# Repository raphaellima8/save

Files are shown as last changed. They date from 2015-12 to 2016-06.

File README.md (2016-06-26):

# SAVE – Um sistema FLOSS autônomo para evitar acidentes envolvendo crianças em carros estacionados

## Sobre
SAVE é um sistema autônomo para evitar acidentes envolvendo crianças em carros estacionados.

## Organização dos diretórios
1. src: Código fonte do firmware e esquemáticos do sistema
	* firmware:   Código fonte do firmware
	* schematics: Arquivos de projeto (software Eagle) dos esquemáticos e layout da PCB

2. dist: Arquivos de distribuição
	* firmware: Versão .hex do firmware para gravação na placa Arduino UNO
	* schematics: Versões em PDF do esquemáticos e layouts da PCB para impressão

## Contato
* Raphael Lima: raphael.aolima8 at gmail dot com

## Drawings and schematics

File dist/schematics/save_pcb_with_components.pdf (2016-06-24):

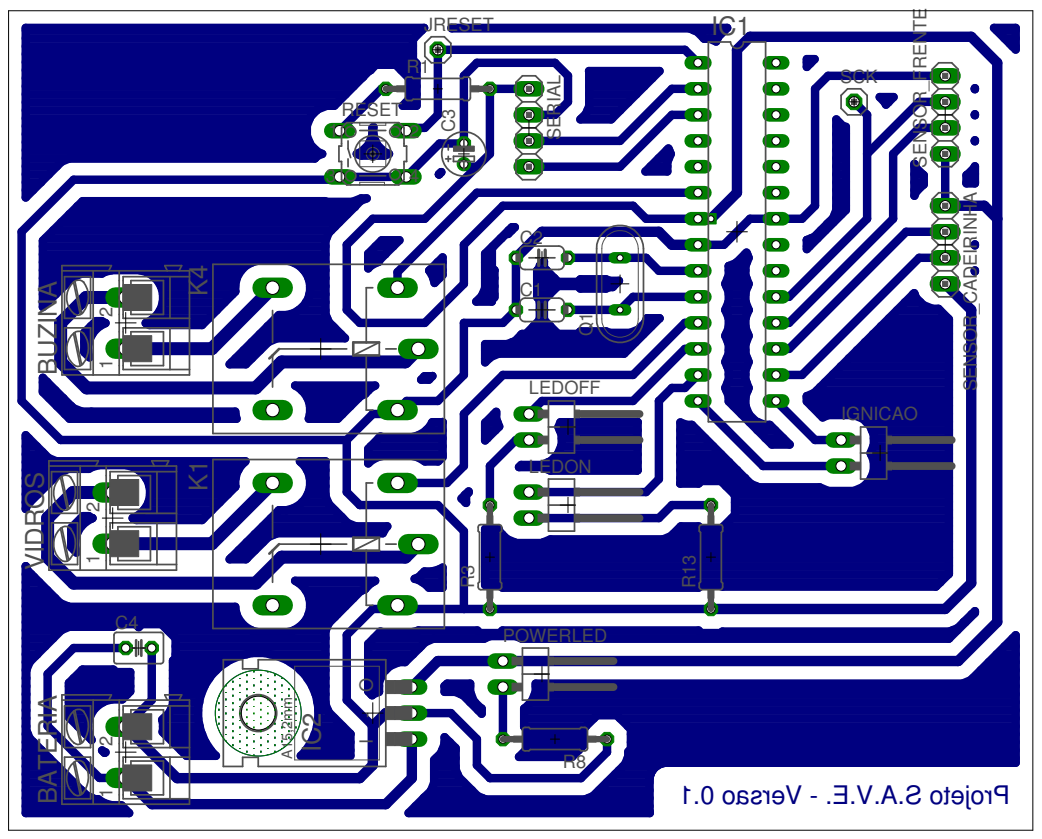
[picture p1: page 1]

11. 0 oasr eV- . E. V. A. S ot ej or P 2 1 2 A15,2mm 1 2 - I O 1 2 3 4 BATERIA BUZINAC1 C2 C3 C4 IC1 IC2 IGNICAO JRESET K1 K4 LEDOFF LEDON POWERLEDQ1 R1 R13 R3 R8 RESET SCK SENSOR_CADEIRINHA SENSOR_FRENTE SERIAL VIDROS

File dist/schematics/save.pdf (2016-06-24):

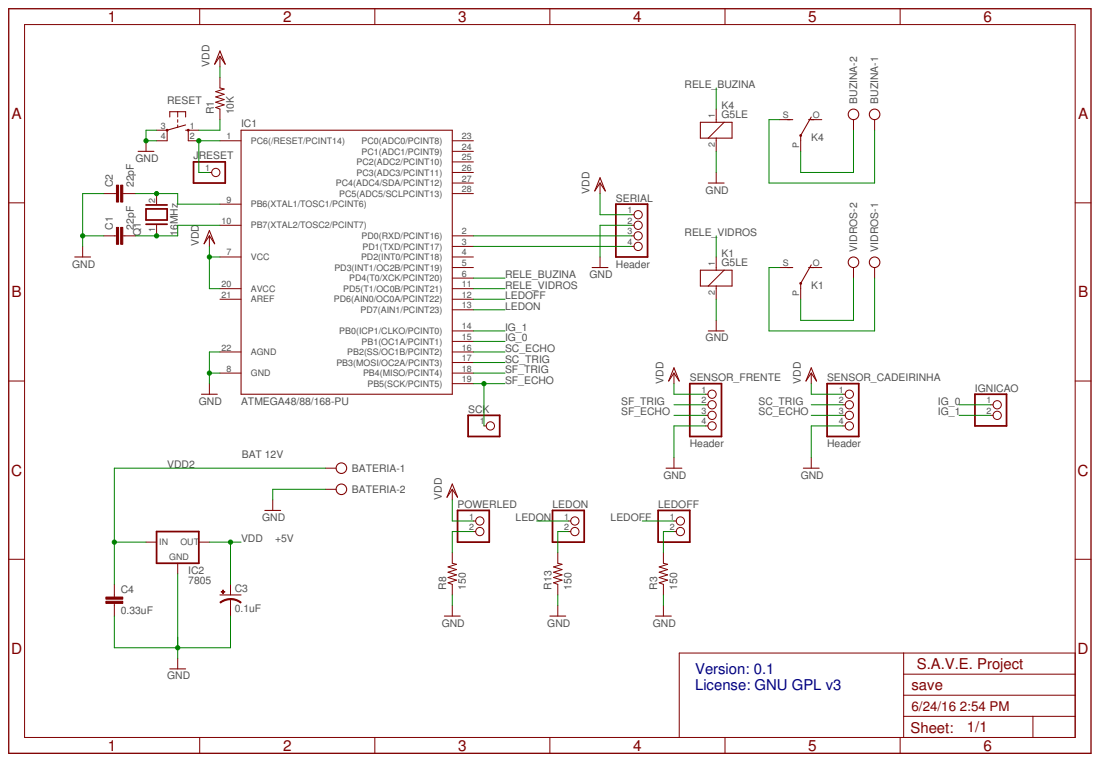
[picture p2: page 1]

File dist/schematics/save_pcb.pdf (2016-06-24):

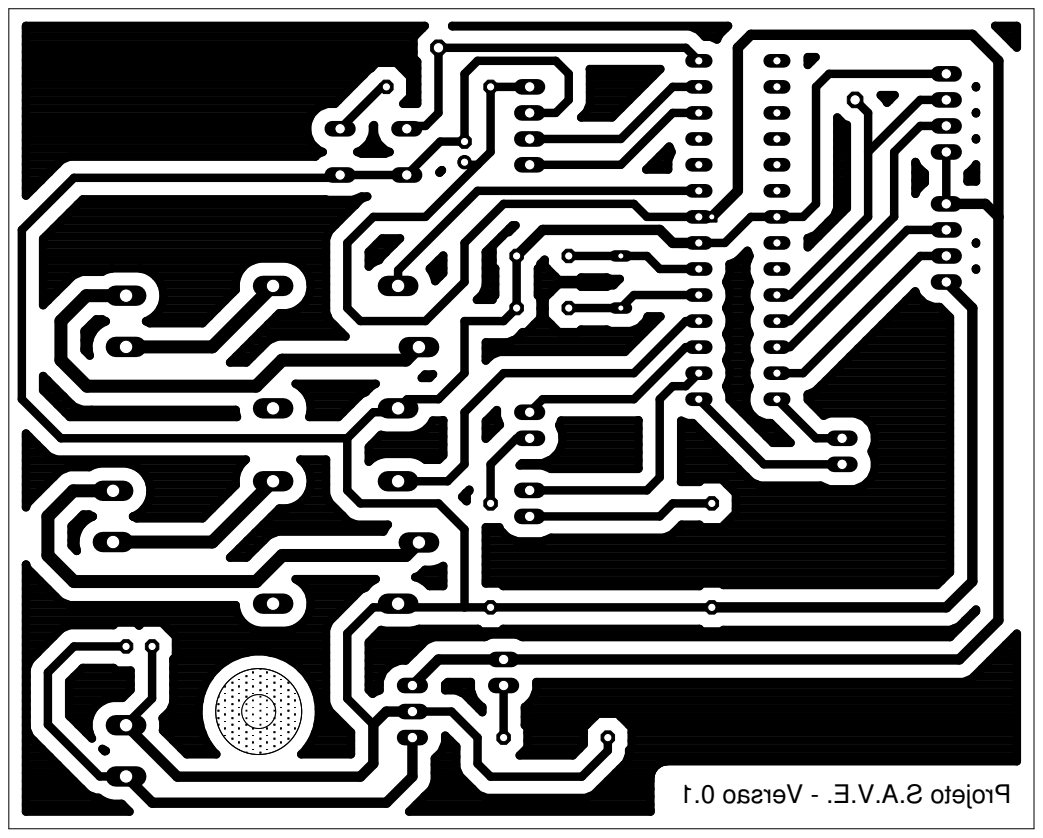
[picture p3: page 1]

1. 0 oasr eV- . E. V. A. S ot ej or P

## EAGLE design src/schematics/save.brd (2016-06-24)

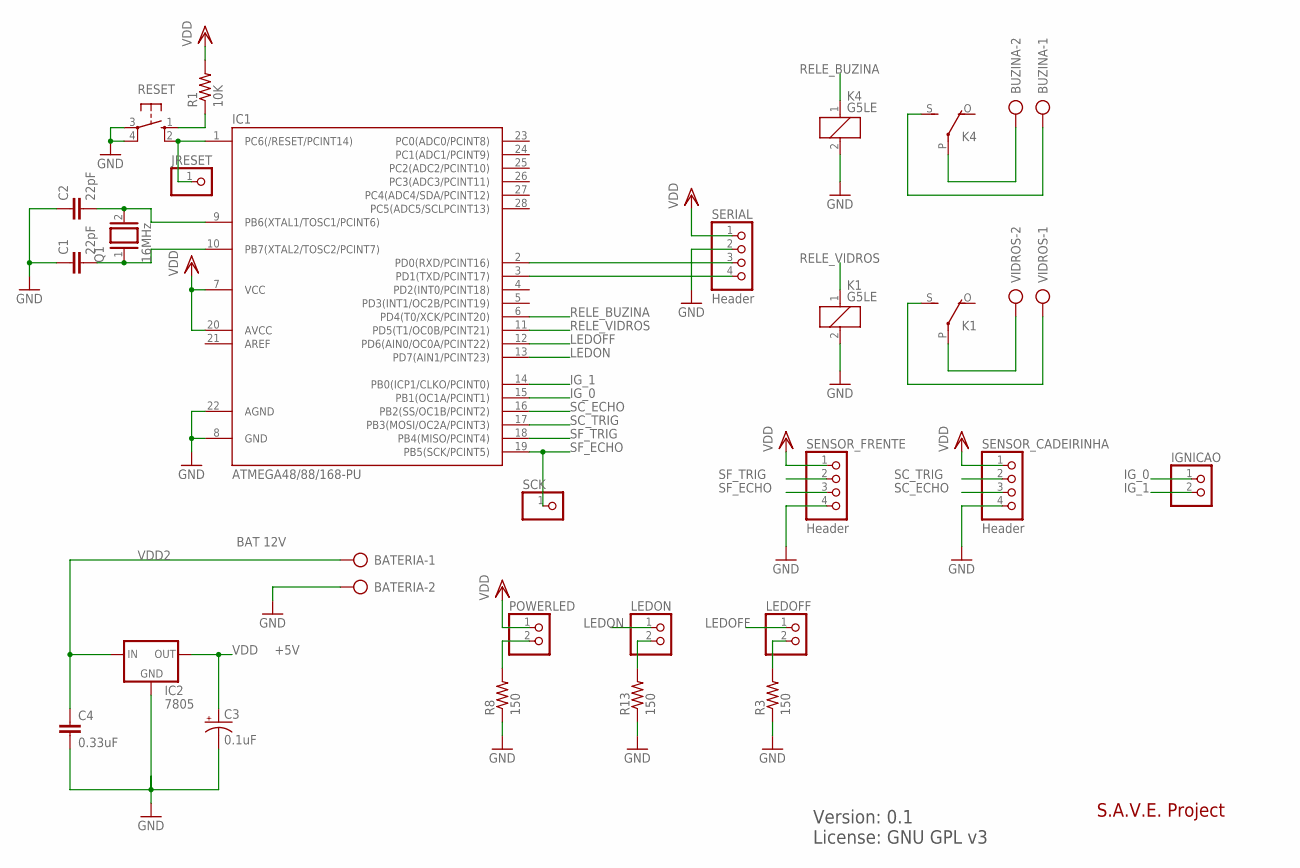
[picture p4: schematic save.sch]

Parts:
BATERIA: AK300/2
BUZINA: AK300/2
C1, C2: 22pF; C050-024X044
C3: 0.1uF; E2-4
C4: 0.33uF; C025-030X050
IC1: ATMEGA48/88/168-PU; DIL28-3
IC2: 7805; 78XXL
IGNICAO: PINHD-1X2/90; 1X02/90
JRESET: PINHD-1X1; 1X01
K1, K4: G5LE
LEDOFF: PINHD-1X2/90; 1X02/90
LEDON: PINHD-1X2/90; 1X02/90
POWERLED: PINHD-1X2/90; 1X02/90
Q1: 16MHz; QS
R1: 10K; 0207/10
R3, R8, R13: 150; 0207/10
RESET: 10-XX; B3F-10XX
SCK: PINHD-1X1; 1X01
SENSOR_CADEIRINHA: Header; 1X04
SENSOR_FRENTE: Header; 1X04
SERIAL: Header; 1X04
VIDROS: AK300/2

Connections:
BUZINA-2: BUZINA.2, K4.P
GND: BATERIA.2, C1.1, C2.1, C3.-, C4.2, IC1.8 (GND), IC1.22 (AGND), IC2.GND, K1.2, K4.2, R3.1, R8.1, R13.1, RESET.3, RESET.4 (P1), SENSOR_CADEIRINHA.4, SENSOR_FRENTE.4, SERIAL.2
IG_0: IC1.15 (PB1(OC1A/PCINT1)), IGNICAO.1
IG_1: IC1.14 (PB0(ICP1/CLKO/PCINT0)), IGNICAO.2
LEDOFF: IC1.12 (PD6(AIN0/OC0A/PCINT22)), LEDOFF.1
LEDON: IC1.13 (PD7(AIN1/PCINT23)), LEDON.1
unnamed: BUZINA.1, K4.S
unnamed: R1.1, RESET.1 (S)
unnamed: IC1.1 (PC6(/RESET/PCINT14)), JRESET.1, RESET.2 (S1)
unnamed: C1.2, IC1.10 (PB7(XTAL2/TOSC2/PCINT7)), Q1.1
unnamed: C2.2, IC1.9 (PB6(XTAL1/TOSC1/PCINT6)), Q1.2
unnamed: K1.S, VIDROS.1
unnamed: LEDOFF.2, R3.2
unnamed: K1.P, VIDROS.2
unnamed: POWERLED.2, R8.2
unnamed: LEDON.2, R13.2
RELE_BUZINA: IC1.6 (PD4(T0/XCK/PCINT20)), K4.1
RELE_VIDROS: IC1.11 (PD5(T1/OC0B/PCINT21)), K1.1
RX: IC1.2 (PD0(RXD/PCINT16)), SERIAL.3
SC_ECHO: IC1.16 (PB2(SS/OC1B/PCINT2)), SENSOR_CADEIRINHA.3
SC_TRIG: IC1.17 (PB3(MOSI/OC2A/PCINT3)), SENSOR_CADEIRINHA.2
SF_ECHO: IC1.19 (PB5(SCK/PCINT5)), SCK.1, SENSOR_FRENTE.3
SF_TRIG: IC1.18 (PB4(MISO/PCINT4)), SENSOR_FRENTE.2
TX: IC1.3 (PD1(TXD/PCINT17)), SERIAL.4
VDD: C3.+, IC1.7 (VCC), IC1.20 (AVCC), IC2.OUT, POWERLED.1, R1.2, SENSOR_CADEIRINHA.1, SENSOR_FRENTE.1, SERIAL.1
VDD2: BATERIA.1, C4.1, IC2.IN

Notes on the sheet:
+5V
BAT 12V
S.A.V.E. Project
Version: 0.1 License: GNU GPL v3

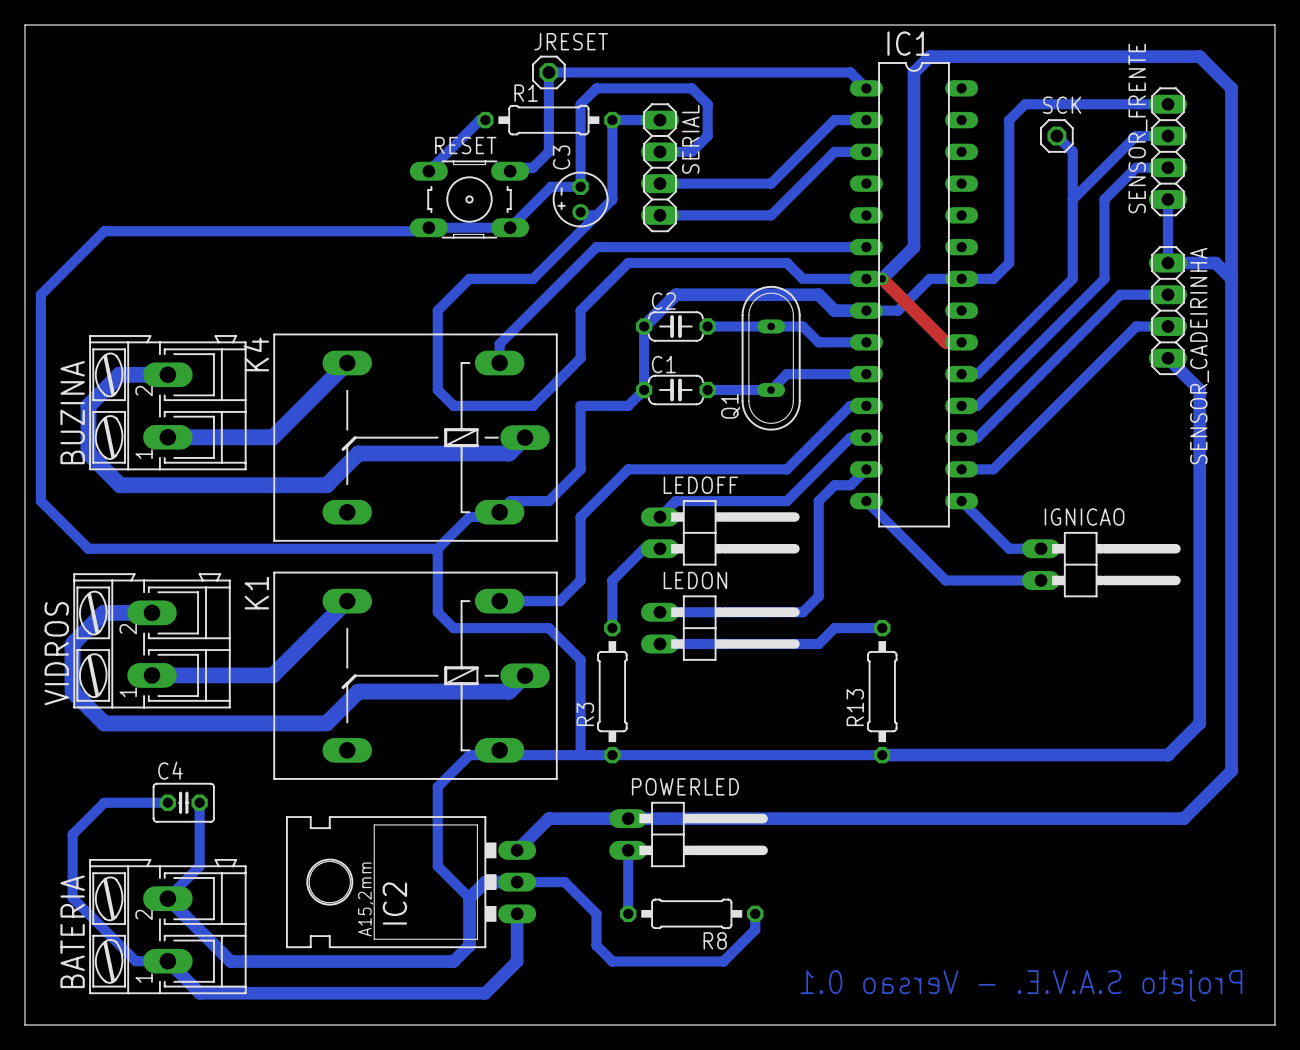
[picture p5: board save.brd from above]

Board: 2 copper layers, 100.0 x 80.0 mm, 26 parts (0 on the bottom side), 26 nets.

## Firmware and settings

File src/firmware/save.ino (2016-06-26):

/*
 * Copyright (C) 2015 Raphael Lima
 * SAVE - Autonomous System for Parked Vehicles
 *
 * This file is part of SAVE.
 *
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
 * You should have received a copy of the GNU General Public License
 * along with this program. If not, see <http://www.gnu.org/licenses/>.
 */

 /*
  Project: SAVE - Autonomous System for Parked Vehicles
  @author Raphael Lima
  @version 0.1
 */

  #define echoPinFront 13
  #define triggerPinFront 12
  #define echoPinBack 11
  #define triggerPinBack 10
  #define dip_1 9
  #define dip_2 8
  #define ledOn 7
  #define ledOff 6
  #define ledWindow 5
  #define buzzer 4
  const int weightPin = A0;

  int distance = 0;
  int state = 0;
  int distances[30];
  const double CONFIDENCE_LEVEL = 1.96;
  double initialDistanceFront = 0;
  double initialDistanceBack = 0;
  double finalDistanceFront = 0;
  double finalDistanceBack = 0;
  boolean cicle = true;
  double confidenceInterval[2];
  int filtratedDistance[30];
  int weight = 0;

  int bin2int(int numValues, ...);
  int powint(int base, int exponent);
  void carStatus(int action);
  void activateActuators(boolean atdr);
  void shutdown();
  int refineDistanceValues(int distance[], int size);
  int getDistance(int trigger, int echo);
  double calculateVariance(int distancesAverages[], int average);
  double standardDeviation(double variance);
  void getConfidenceInterval(int dists[]);
  int calculateAverage(int dist[]);
  int toMeasureDistance(int trigger, int echo);
  int getWeight();

  void setup()
  {
    Serial.begin (9600);
    pinMode(triggerPinBack, OUTPUT);
    pinMode(echoPinBack, INPUT);
    pinMode(triggerPinFront, OUTPUT);
    pinMode(echoPinFront, INPUT);
    pinMode(ledOn, OUTPUT);
    pinMode(ledOff, OUTPUT);
    pinMode(buzzer, OUTPUT);
    pinMode(ledWindow, OUTPUT);
    pinMode(dip_1, INPUT_PULLUP);
    pinMode(dip_2, INPUT_PULLUP);
  }
/*
  Read the DIP switch configuration and convert the result to binary
  @param amount of pins that will be read
  @param pins that will be read
  @return the numerical value of the color code.
*/
  int bin2int ( int numValues, ... )
  {
    int total = 0;
    va_list values;
    va_start(values, numValues);

    for( ; numValues > 0; numValues--)
          if(!(digitalRead(va_arg(values, int))) )
              total += powint(2, numValues-1);

    va_end(values);
    return total;
  }

  int powint(int base, int exponent)
  {
    int result = 1;
    for( ; exponent > 0; exponent--)
          result *= base;
    return result;
  }

  /*
    Indicates if the car is on or off.
    Case @param equal 0, vehicle is Off, but if @param equal 1, vehicle is on
    @param int 0 or 1 condition that will indicate if vehicle is on or off
  */
  void carStatus(int action)
  {
    switch(action){
      case 0:
        digitalWrite(ledOn, LOW);
        digitalWrite(ledOff, HIGH);
      break;

      case 1:
        digitalWrite(ledOn, HIGH);
        digitalWrite(ledOff, LOW);
      break;
    }
  }

  /*
  Activates the actuators as the buzzer and LED's. Only stop when @param atdr is
  false and DIP switch is at low logic level.
  @param boolean adtr
  */
  void activateActuators(boolean atdr)
  {
    digitalWrite(ledWindow, HIGH);
    delay(6000);
    digitalWrite(ledWindow, LOW);
    while(atdr) {
      tone(buzzer, 1500);
      delay(300);
      noTone(buzzer);
      digitalWrite(ledOff, LOW);
      delay(600);
      digitalWrite(ledOff, HIGH);

      state = bin2int(2, dip_1,dip_2);

      if(state == B010){
        atdr = false;
        cicle = true;
      }
    }
  }

  /*
  Turn off the system and reset the values of the variables
  */
  void shutdown()
  {
    distance = 0;
    initialDistanceFront = 0;
    initialDistanceBack = 0;
    finalDistanceFront = 0;
    finalDistanceBack = 0;
    cicle = true;
  }

  int getWeight()
  {
      return analogRead(weightPin);
  }

  int refineDistanceValues(int distance[], int size)
  {
        int index = 0, average = 0, sum = 0, i = 0;

        if(size == 10){
           while(index < 5){
            distance[index]  =  (distance[i] + distance[i+1]) / 2;
            index++;
           }
           for(int j = 0; j < 5; j++){
            sum = sum + distance[j];
           }
           average = sum / 5;
           return average;
        } else {
            while(index < 10){
              distance[index]  =  (distance[i] + distance[i+1] + distance[i+2]) / 3;
              index++;
              i = i+3;
            }
            refineDistanceValues(distance, 10);
        }
  }

  int getDistance(int trigger, int echo)
  {
    for(int i = 0; i < 30; i++){
        distances[i] = toMeasureDistance(trigger, echo);
        Serial.print(distances[i]);
        Serial.print(" | ");
    }
    int averages = refineDistanceValues(distances, 30);
    Serial.print("Average: ");
    Serial.println(averages);
    return averages;
  }

  double calculateVariance(int distancesAverages[], int average)
  {
    double variance = 0;
    for(int i = 0; i < 30; i++){
       variance = variance + pow((distancesAverages[i] - average), 2);
       Serial.print(variance);
       Serial.print(" | ");
    }
    Serial.println();
    Serial.print("Variance ");
    Serial.println(variance/30);
    return variance/30;
  }

  double standardDeviation(double variance)
  {
    Serial.print("Standard Deviation ");
    Serial.println(sqrt(variance));
    return sqrt(variance);
  }

  void getConfidenceInterval(int dists[])
  {
    int average = refineDistanceValues(dists, 30);
    Serial.println("==========================================================");
    Serial.print("Total Average: " );
    Serial.println(average);
    double variance = calculateVariance(dists, average);
    double deviation = standardDeviation(variance);

    confidenceInterval[0] = (average - CONFIDENCE_LEVEL) * (variance / deviation);
    confidenceInterval[1] = (average + CONFIDENCE_LEVEL) * (variance / deviation);
  }

  int calculateAverage(int dist[])
  {
    int sum = 0;
    for(int i = 0; i < 30; i++){
        sum = sum + dist[i];
    }
    return (sum/30);
  }

  void loop()
  {
    state = bin2int(2, dip_1,dip_2);

    switch(state){
      case(B011)://Dois pinos nivel alto
          if(cicle){
            carStatus(1);
            for(int i = 0; i < 30; i++){
              filtratedDistance[i] = getDistance(triggerPinFront, echoPinFront);
              delay(3000);
            }
            getConfidenceInterval(filtratedDistance);
            Serial.print("Inferior Limit: ");
            Serial.println(confidenceInterval[0]);
            Serial.print("Upper Limit: ");
            Serial.println(confidenceInterval[1]);
            initialDistanceFront = confidenceInterval[0];
            for(int i = 0; i < 30; i++){
              filtratedDistance[i] = getDistance(triggerPinBack, echoPinBack);
              delay(3000);
            }
            getConfidenceInterval(filtratedDistance);
            Serial.print("Inferior Limit: ");
            Serial.println(confidenceInterval[0]);
            Serial.print("Upper Limit: ");
            Serial.println(confidenceInterval[1]);
            initialDistanceBack = confidenceInterval[0];
            weight = getWeight();
            cicle = false;
          }
      break;

      case(B000): //Dois pinos nivel baixo
        carStatus(0);
        delay(5000); //5 segundos, o ideal seria por volta de 2 minutos.
            for(int i = 0; i < 30; i++){
              filtratedDistance[i] = getDistance(triggerPinFront, echoPinFront);
              delay(3000);
            }
            getConfidenceInterval(filtratedDistance);
            Serial.print("Inferior Limit: ");
            Serial.println(confidenceInterval[0]);
            Serial.print("Upper Limit: ");
            Serial.println(confidenceInterval[1]);
            finalDistanceFront = confidenceInterval[0];
            for(int i = 0; i < 30; i++){
              filtratedDistance[i] = getDistance(triggerPinBack, echoPinBack);
              delay(3000);
            }
            getConfidenceInterval(filtratedDistance);
            Serial.print("Inferior Limit: ");
            Serial.println(confidenceInterval[0]);
            Serial.print("Upper Limit: ");
            Serial.println(confidenceInterval[1]);
            finalDistanceBack = confidenceInterval[0];
            weight = getWeight();
            if(finalDistanceFront > initialDistanceFront && finalDistanceBack <= initialDistanceBack && weight > 0){
                activateActuators(true);
            } else if (finalDistanceFront > initialDistanceFront && finalDistanceBack >= initialDistanceBack && weight > 0){
                activateActuators(true);
            } else {
                shutdown();
            }
      break;

      case(B010):
            shutdown();
      break;

      case(B001):

      break;

      }
    delay(1000);
  }

  int toMeasureDistance(int trigger, int echo)
  {
    long duration, distance;

    digitalWrite(trigger, LOW);  // Added this line

    delayMicroseconds(2); // Added this line

    digitalWrite(trigger, HIGH);

    delayMicroseconds(10); // Added this line

    digitalWrite(trigger, LOW);

    duration = pulseIn(echo, HIGH);
    distance = (duration/2) / 29.1;

    return distance;
  }

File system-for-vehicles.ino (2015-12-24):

  /*
 * Copyright (C) 2015 Raphael Lima
 * S.A.V.E - It is a software that manages the hardware that make up an entire autonomic system.
 *
 * This file is part of S.A.V.E.
 *
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
 * You should have received a copy of the GNU General Public License
 * along with this program. If not, see <http://www.gnu.org/licenses/>.
 */
 
  #define pinoEchoFrente 13
  #define pinoTriggerFrente 12
  #define pinoEchoTras 11
  #define pinoTriggerTras 10
  #define dip_1 9
  #define dip_2 8
  #define ledLigado 7
  #define ledDesligado 6
  #define ledVidro 5
  #define buzzer 4
  
  int distancia = 0;
  int estado = 0;
  int distancias[30];
  double nivelConfianca = 1.96;
  double distanciaInicialFrontal = 0;
  double distanciaInicialTraseira = 0;
  double distanciaFinalFrontal = 0;
  double distanciaFinalTraseira = 0;
  boolean ciclo = true;
  double intervaloConfianca[2];
  int distanciaFiltrada[30];
  
  void setup() 
  {
    Serial.begin (9600);
    pinMode(pinoTriggerTras, OUTPUT);
    pinMode(pinoEchoTras, INPUT);
    pinMode(pinoTriggerFrente, OUTPUT);
    pinMode(pinoEchoFrente, INPUT);
    pinMode(ledLigado, OUTPUT);
    pinMode(ledDesligado, OUTPUT);
    pinMode(buzzer, OUTPUT);
    pinMode(ledVidro, OUTPUT);
    pinMode(dip_1, INPUT_PULLUP);
    pinMode(dip_2, INPUT_PULLUP);
  }
  
  int bin2int(int numValues, ...)
  { //Primeiro parametro e a quantidade de pinos que serao lidos, os "n" seguintes sao os pinos a serem lidos
    int total = 0;
    va_list values;
    va_start(values, numValues);
    
    for( ; numValues > 0; numValues--)
          if(!(digitalRead(va_arg(values, int))) )
              total += powint(2, numValues-1);
              
    va_end(values);
    return total;
  }
  
  int powint(int base, int exponent)
  {
    int result = 1;
    for( ; exponent > 0; exponent--)
          result *= base;
    return result;
  }
  
  void statusCarro(int acao)
  {
    switch(acao){
      case 0:
        digitalWrite(ledLigado, LOW);
        digitalWrite(ledDesligado, HIGH);
        break;
        
        case 1:
          digitalWrite(ledLigado, HIGH);
          digitalWrite(ledDesligado, LOW);
          break;
    }
  }
  
  void acionarAtuadores(boolean atdr)
  {
    digitalWrite(ledVidro, HIGH);
    delay(6000);
    digitalWrite(ledVidro, LOW);
      while(atdr) {
        tone(buzzer, 1500);
        delay(300);
        noTone(buzzer);
        digitalWrite(ledDesligado, LOW);
        delay(600);
        digitalWrite(ledDesligado, HIGH);
        
        estado = bin2int(2, dip_1,dip_2);
       
        if(estado == B010){
          atdr = false;
          ciclo = true;
        }
      }
  }
  
   
  
  void desligarSistema()
  {
    int distancia = 0;
    double distanciaInicialFrontal = 0;
    double distanciaInicialTraseira = 0;
    double distanciaFinalFrontal = 0;
    double distanciaFinalTraseira = 0;
    boolean ciclo = true;
  }
  
  int filtrarValoresDistancia(int distancia[], int tamanho)
  {
        int indice = 0;
        int media = 0;
        int soma = 0;
        int i = 0;      
        
        if(tamanho == 10){
           
           while(indice < 5){
               distancia[indice]  =  (distancia[i] + distancia[i+1]) / 2;
               indice++;
           }
           
           for(int j = 0; j < 5; j++){
             soma = soma + distancia[j];
           }   
        
           media = soma / 5;
           return media;
        
        } 
        else
        {
          while(indice < 10){
            distancia[indice]  =  (distancia[i] + distancia[i+1] + distancia[i+2]) / 3;
            indice++;
            i = i+3;
          }
             filtrarValoresDistancia(distancia, 10);
        }
  }
  
int obterDistancia(int trigger, int echo){
    for(int i = 0; i < 30; i++){
        distancias[i] = medirDistancia(trigger, echo);
        Serial.print(distancias[i]);
        Serial.print(" | ");
    }
    int medias = filtrarValoresDistancia(distancias, 30);
    Serial.print("Media: ");
    Serial.println(medias);
    return medias;
  }
  
  double calcularVariancia(int mediasDistancia[], int media){
    double variancia = 0;
    for(int i = 0; i < 30; i++){
       variancia = variancia + pow((mediasDistancia[i] - media), 2);
       Serial.print(variancia);
       Serial.print(" | ");
    }
    Serial.println();
    Serial.print("Variancia ");
    Serial.println(variancia/30);
    return variancia/30;
  }
  
  double desvioPadrao(double variancia){  
    Serial.print("Desvio Padrao ");
    Serial.println(sqrt(variancia));
    return sqrt(variancia);
  }
  
  void intervaloDeConfianca(int dists[]){
    int media = filtrarValoresDistancia(dists, 30);
    Serial.println("==================================================================================================");
    Serial.print("MEDIA TOTAL: " );
    Serial.println(media);
    double variancia = calcularVariancia(dists, media);
    double desvio = desvioPadrao(variancia);
    
    intervaloConfianca[0] = (media - nivelConfianca) * (variancia / desvio);
    intervaloConfianca[1] = (media + nivelConfianca) * (variancia / desvio);
  }
  
  int calcularMedia(int dist[]){
    int soma = 0;
    for(int i = 0; i < 30; i++){
        soma = soma + dist[i];
    }
    return (soma/30);
  }
  
  void loop() 
  { 
    estado = bin2int(2, dip_1,dip_2);
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

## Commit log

2016-06-24 Schematics and deploy files added.
    - Add schematics sources
    - Add schematics pdf files
    - Add information to README
    - Add hex version of firmware
    [save.brd, save.sch]
2016-06-26 Prototype functions added
2016-06-26 weight sensor function added
2016-06-26 Fix conditional of detection
    [save.ino]

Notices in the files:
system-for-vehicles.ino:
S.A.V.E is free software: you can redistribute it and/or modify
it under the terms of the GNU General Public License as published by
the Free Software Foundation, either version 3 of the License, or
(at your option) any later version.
